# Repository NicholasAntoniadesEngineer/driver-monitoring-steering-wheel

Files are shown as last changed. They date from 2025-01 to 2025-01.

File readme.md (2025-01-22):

# ECG Driver Monitoring Steering Wheel (2022)

## Overview
As part of an Innovate UK funded project (May 2021), this project explores the feasibility of recording heart rate variability (HRV) data of a driver in a vehicle using bipotential recording directly from the steering wheel. The system faces unique challenges in dealing with electromagnetic interference, noise management, and signal consistency as drivers move their hands along and occasionally off the steering wheel.

The videos folder contains demonstrations of the concept working.

## Project Goals
- Research and analyze vehicle ambient and driver-movement noise within the expected application setting
- Develop a proof-of-concept demonstrator comprising:
  - Multiple steering wheel cover versions with different electrode technologies
  - Simple steering wheel test rig for tabletop placement
  - Biopotential capture electronics with user display
  - R-peak extraction and HRV calculation capabilities

## System Architecture

### Hardware Components
- Raspberry Pi 4B (main controller)
- ADS1293 ECG sensor
- ADS1241 ADC for grip force monitoring
- Bluetooth Low Energy (BLE) communication module
- Custom steering wheel electrodes
- Display screen for real-time visualization

### Software Components
1. **Data Acquisition**
   - BLE communication handling
   - ECG signal sampling (500Hz)
   - Grip force monitoring
   - Real-time data processing

2. **Signal Processing**
   - Bandpass filtering
   - R-peak detection
   - HRV calculation
   - Noise reduction algorithms

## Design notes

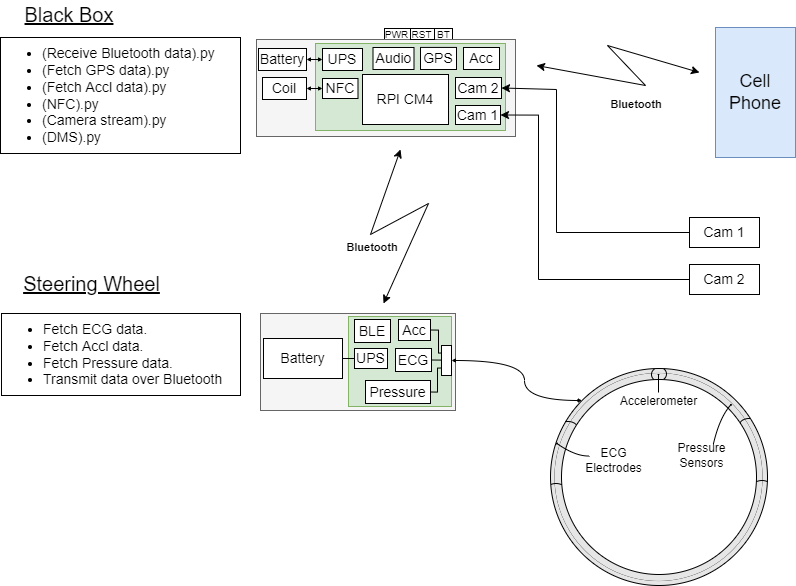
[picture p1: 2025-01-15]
driver_monitoring_system_overview.png

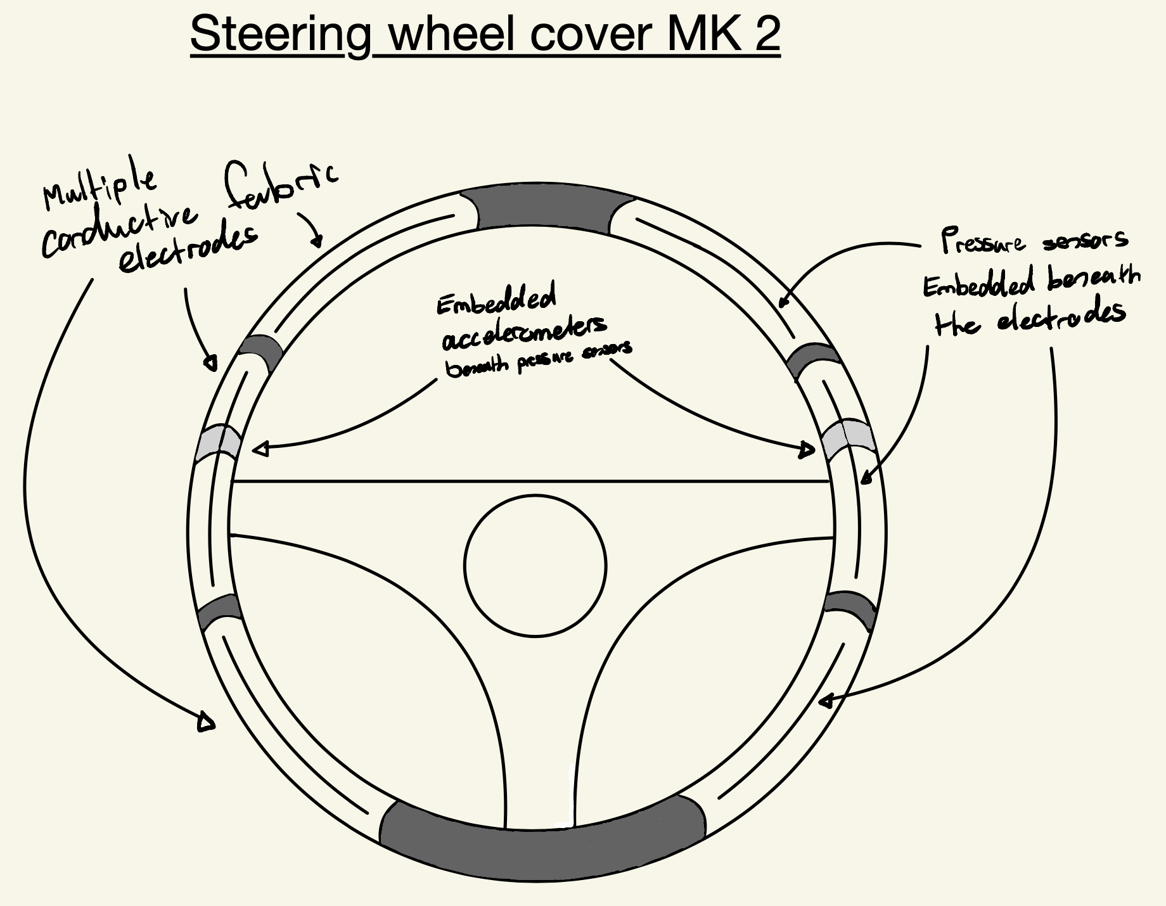
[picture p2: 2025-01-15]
steering_wheel_v2.png

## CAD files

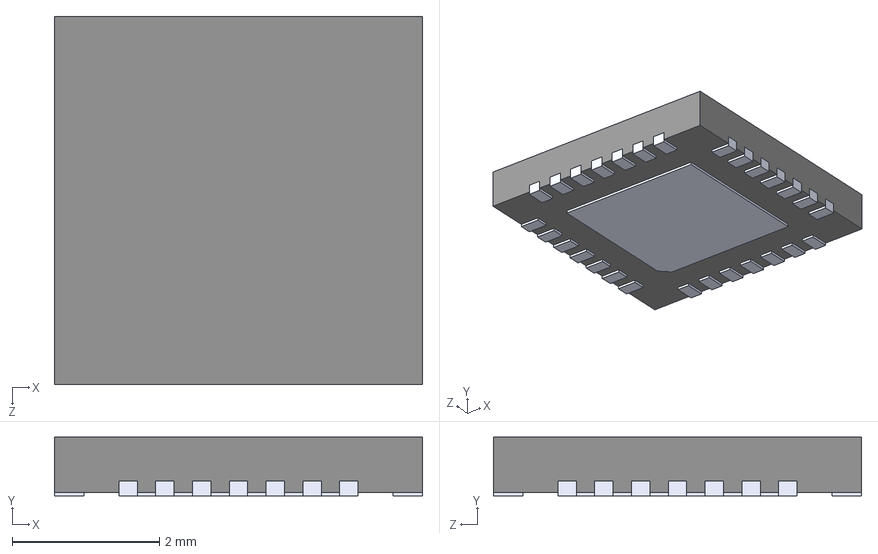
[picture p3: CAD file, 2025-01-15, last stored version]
rpi_hat_schematics/ADS1293CISQ_NOPB/ADS1293CISQ_NOPB.step
5.00 x 0.8 x 5.00 mm

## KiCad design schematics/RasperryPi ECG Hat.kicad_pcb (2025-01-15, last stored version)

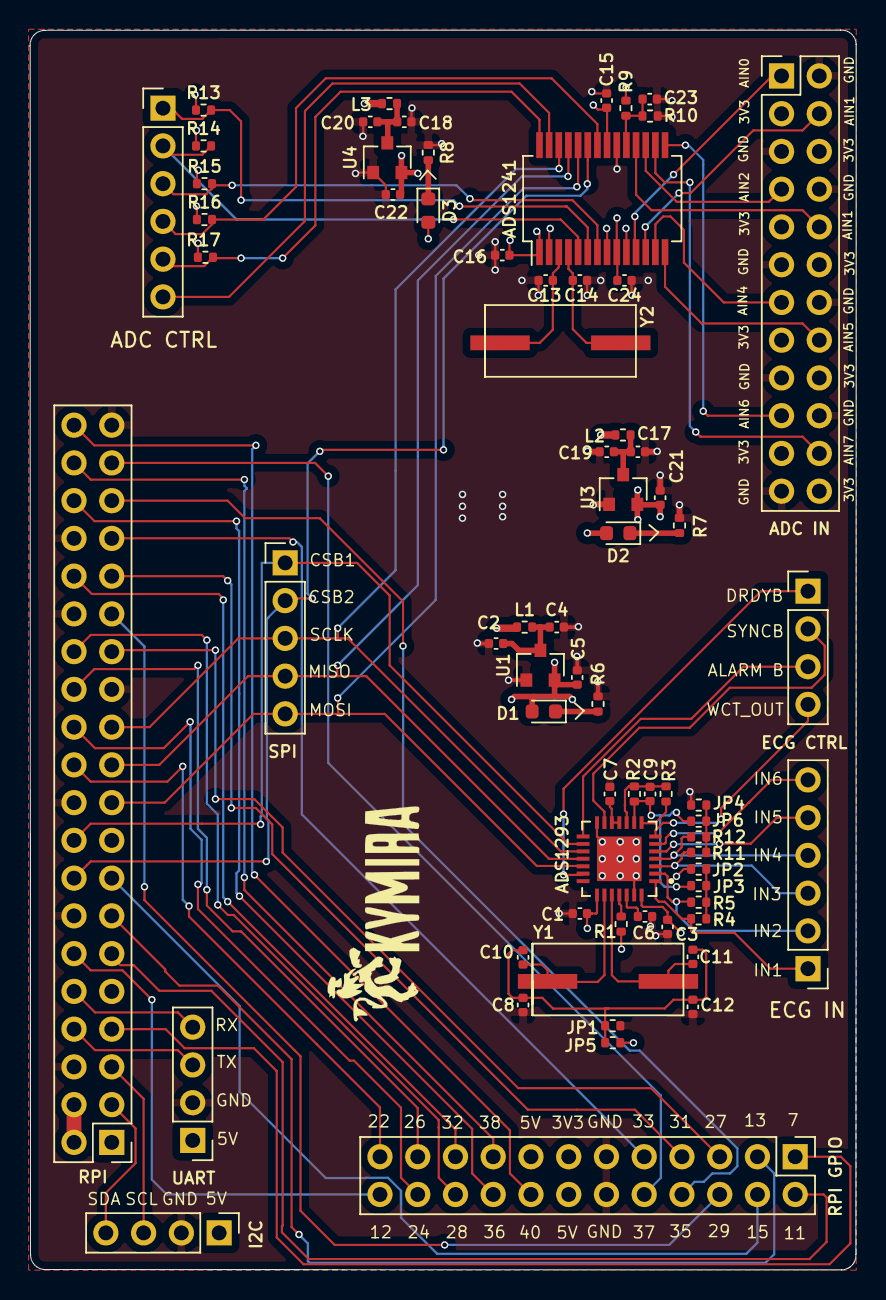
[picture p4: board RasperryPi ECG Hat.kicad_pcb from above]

Board: 4 copper layers, 55.6 x 83.4 mm, 69 parts (0 on the bottom side), 78 nets.

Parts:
ADC CTRL: ADC Control; PinHeader_1x06_P2.54mm_Vertical
ADC IN: ADC Input; PinHeader_2x12_P2.54mm_Vertical
ADS1241: ADS1241; SSOP-28_5.3x10.2mm_P0.65mm
ADS1293: ADS1293; WQFN 28
C1, C3, C7, C8, C12, C15, C16, C23, C24: 100n; C_0402_1005Metric
C2, C17, C18: 10u; C_0402_1005Metric
C4, C5, C19, C20, C21, C22: 4.7u; C_0402_1005Metric
C6: 1u; C_0402_1005Metric
C9: 1n; C_0402_1005Metric
C10, C11, C13, C14: 18p; C_0402_1005Metric
D1, D2, D3: LED
ECG CTRL: ECG Control; PinHeader_1x04_P2.54mm_Vertical
ECG IN: ECG Input; PinHeader_1x06_P2.54mm_Vertical
I2C: I2C; PinHeader_1x04_P2.54mm_Vertical
JP1, JP2, JP3, JP4, JP5, JP6: Jumper; R_0402_1005Metric
L1, L2, L3: INDUCTOR; R_0402_1005Metric
R1: 1M; R_0402_1005Metric
R2, R4, R5, R11, R12: 10M; R_0402_1005Metric
R3, R9, R10, R13, R14, R15, R16, R17: 10k; R_0402_1005Metric
R6, R7, R8: 600; R_0402_1005Metric
RPI: Raspberry_Pi_4; PinHeader_2x20_P2.54mm_Vertical
RPI GPIO: Extra pins; PinHeader_2x12_P2.54mm_Vertical
SPI: SPI; PinHeader_1x05_P2.54mm_Vertical
U1, U3, U4: MCP1703A; SOT-23
UART: UART; PinHeader_1x04_P2.54mm_Vertical
Y1, Y2: 4.096; SMD_Crystal_2_pin_11.3_4.5

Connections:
3V3: RPI.1, RPI GPIO.13
5V: I2C.1, L1.1, L2.1, L3.1, RPI.2, RPI.4, RPI GPIO.14, RPI GPIO.15, UART.1
7: RPI.7, RPI GPIO.1
11: RPI.11, RPI GPIO.2
12: RPI.12, RPI GPIO.24
13: RPI.13, RPI GPIO.3
15: RPI.15, RPI GPIO.4
22: RPI.22, RPI GPIO.23
24: RPI.24, RPI GPIO.22
26: RPI.26, RPI GPIO.21
27: RPI.27, RPI GPIO.5
28: RPI.28, RPI GPIO.20
29: RPI.29, RPI GPIO.6
31: RPI.31, RPI GPIO.7
32: RPI.32, RPI GPIO.19
33: RPI.33, RPI GPIO.9
35: RPI.35, RPI GPIO.8
36: RPI.36, RPI GPIO.18
37: RPI.37, RPI GPIO.10
38: RPI.38, RPI GPIO.17
40: RPI.40, RPI GPIO.16
ADC_3v3: ADS1241.1, ADS1241.9, ADS1241.21, C15.1, C16.1, C22.1, C24.1, D3.1, R9.1, R13.1, R14.1, R15.1, R16.1, R17.1, U4.2
AIN0: ADC IN.1, ADS1241.11
AIN1: ADC IN.4, ADS1241.12
AIN2: ADC IN.7, ADS1241.17
AIN3: ADC IN.10, ADS1241.18
AIN4: ADC IN.13, ADS1241.13
AIN5: ADC IN.16, ADS1241.14
AIN6: ADC IN.19, ADS1241.15
AIN7: ADC IN.22, ADS1241.16
ALARMB: ADS1293.15, ECG CTRL.3
BUFEN: ADC CTRL.5, ADS1241.28, R17.2
CSB1: ADS1293.16, RPI.18, SPI.1
CSB2: ADS1241.23, RPI.16, SPI.2
DRDY: ADC CTRL.6, ADS1241.27
DRDYB: ADS1293.20, ECG CTRL.1
ECG_3v3: ADS1293.22, ADS1293.28, C1.1, C3.1, C5.1, D1.1, JP5.2, R1.1, U1.2
Earth: ADC IN.2, ADC IN.5, ADC IN.8, ADC IN.11, ADC IN.14, ADC IN.17, ADC IN.20, ADC IN.23, ADS1241.2, ADS1241.8, ADS1241.10, ADS1241.20, ADS1293.14, ADS1293.27, ADS1293.29, C1.2, C2.2, C3.2, C4.2, C5.2, C6.2, C7.2, C8.2, C12.2, C13.2, C14.2, C15.2, C16.2, C17.2, C18.2, C19.2, C20.2, C21.2, C22.2, C23.2, C24.2, I2C.2, JP1.1, JP2.1, JP4.1, R6.2, R7.2, R8.2, R10.2, RPI.6, RPI.9, RPI.14, RPI.20, RPI.25, RPI.30, RPI.34, RPI.39, RPI GPIO.11, RPI GPIO.12, U1.1, U3.1, U4.1, UART.2
I2C1_SCL: I2C.3, RPI.5
I2C1_SDA: I2C.4, RPI.3
IN1: ADS1293.1, ECG IN.1, R4.2
IN2: ADS1293.2, ECG IN.2, R5.2
IN3: ADS1293.3, ECG IN.3, R11.2
IN4: ADS1293.4, ECG IN.4, R12.2
IN5: ADS1293.5, ECG IN.5
IN6: ADS1293.6, ECG IN.6
MISO: ADS1241.25, ADS1293.18, RPI.21, SPI.4
MOSI: ADS1241.24, ADS1293.19, RPI.19, SPI.5
unnamed: C2.1, C4.1, L1.2, U1.3
unnamed: ADS1293.26, C6.1
unnamed: ADS1293.11, ADS1293.12, C7.1
unnamed: ADS1293.10, C9.2, R2.2, R3.2
unnamed: C8.1, C10.1, C11.1, C12.1, JP1.2, JP5.1
unnamed: ADS1293.23, C10.2, Y1.1
unnamed: ADS1293.24, C11.2, Y1.2
unnamed: ADS1241.3, C13.1, Y2.1
unnamed: ADS1241.4, C14.1, Y2.2
unnamed: C17.1, C19.1, L2.2, U3.3
unnamed: C18.1, C20.1, L3.2, U4.3
unnamed: ADS1241.19, C23.1, R9.2, R10.1
unnamed: D1.2, R6.1
unnamed: D2.2, R7.1
unnamed: D3.2, R8.1
unnamed: JP2.2, JP3.1, R4.1, R5.1
unnamed: JP4.2, JP6.1, R11.1, R12.1
unnamed: ADS1293.25, R1.2
unnamed: ADS1293.8, R3.1
POL: ADC CTRL.4, ADS1241.22, R16.2
RLDOUT: ADS1293.9, C9.1, JP3.2, JP6.2, R2.1
SCLK: ADS1241.26, ADS1293.17, RPI.23, SPI.3
SYNCB: ADS1293.13, ECG CTRL.2
Strain_3v3: ADC IN.3, ADC IN.6, ADC IN.9, ADC IN.12, ADC IN.15, ADC IN.18, ADC IN.21, ADC IN.24, C21.1, D2.1, U3.2
UART_RX: RPI.10, UART.4
UART_TX: RPI.8, UART.3
WCT_OUT: ADS1293.7, ECG CTRL.4
~DSYNC: ADC CTRL.1, ADS1241.6, R13.2
~PDWN: ADC CTRL.3, ADS1241.7, R15.2
~RESET: ADC CTRL.2, ADS1241.5, R14.2

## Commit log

2022-02-09 Including schematic
2022-07-28 Videos of the ECG and Pressure sensor in action
2025-01-15 adding schematic
    [ADS1293CISQ_NOPB.step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]
2025-01-16 clearing up repo
    [ADS1293CISQ_NOPB.step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]
2025-01-16 moving files around
    [ADS1293CISQ_NOPB.step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]
2025-01-22 compress schematics to save sapce
    [ADS1293CISQ_NOPB.step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]
